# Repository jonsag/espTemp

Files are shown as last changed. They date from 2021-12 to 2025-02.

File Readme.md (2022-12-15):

# espTemp

An ESP-01 module with a DHT22 temperature sensor  
KiCad/espTemp/espTemp.png
Modified from [https://randomnerdtutorials.com/esp8266-dht11dht22-temperature-and-humidity-web-server-with-arduino-ide/](https://randomnerdtutorials.com/esp8266-dht11dht22-temperature-and-humidity-web-server-with-arduino-ide/)

## Hardware

Build according to schematics in KiCAD.  

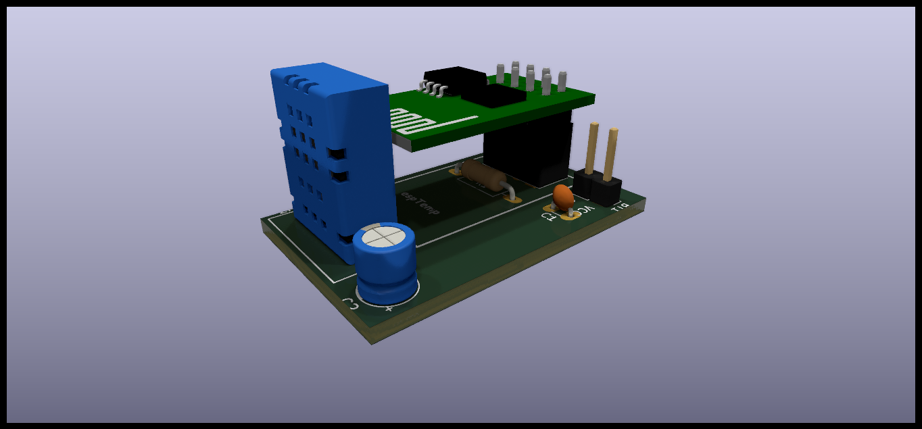
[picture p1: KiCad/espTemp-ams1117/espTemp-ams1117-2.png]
with AMS1117 3dView

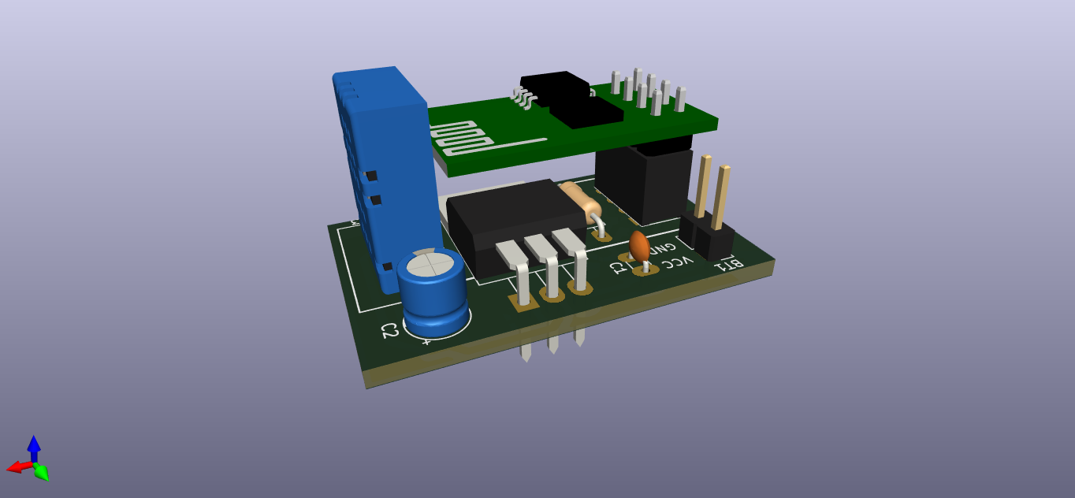
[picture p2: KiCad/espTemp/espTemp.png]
with LM78xx 3dView

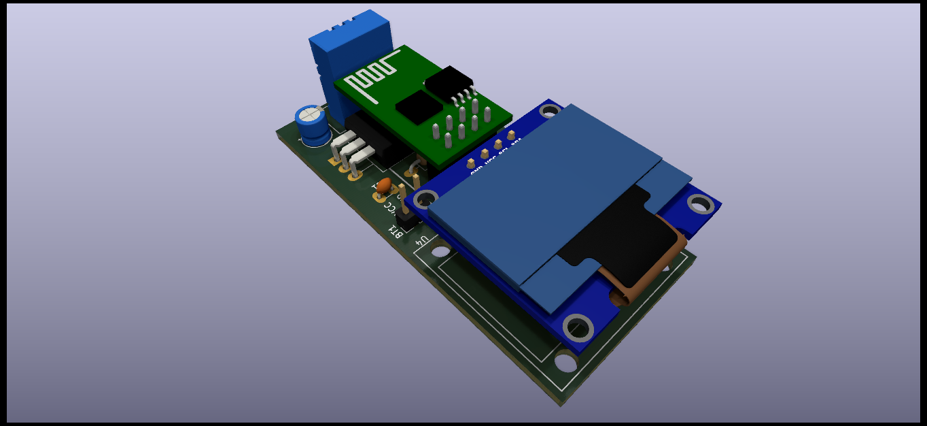
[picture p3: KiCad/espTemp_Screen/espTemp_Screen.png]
with screen 3dView


## Software

Copy file wifiConfig.h.template in espTemp-PIO/src to wifiConfig.h.  
>$ cp espTemp-PIO/src/wifiConfig.h.template espTemp-PIO/src/wifiConfig.h

Edit the new file, entering your SSID and password.  
Compile and upload.  

Connect via serial (while module is still in  programmer) to find out IP and port.  

## Pins on the ESP-01

Pin         Input       Output  
5   GPIO0   pulled up   OK          connected to FLASH button, boot fails if pulled LOW  
2   GPIO1   TX pin      OK          HIGH at boot, debug output at boot, boot fails if pulled LOW  
3   GPIO2   pulled up   OK          HIGH at boot, connected to on-board LED, boot fails if pulled LOW  
7   GPIO3   OK          RX pin      HIGH at boot

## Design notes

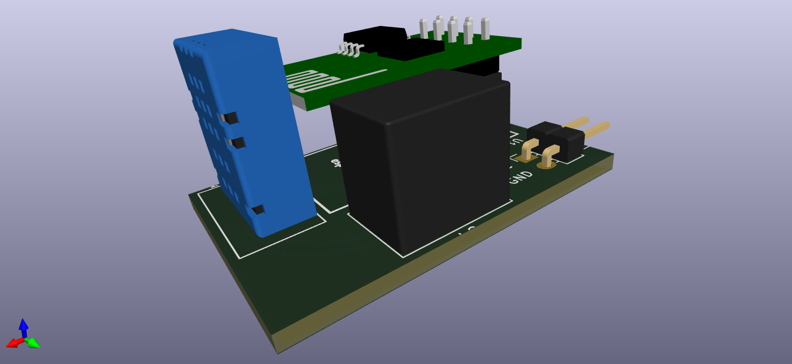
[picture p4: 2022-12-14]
KiCad/espTemp_R-78xx/espTemp_R-78xx.png

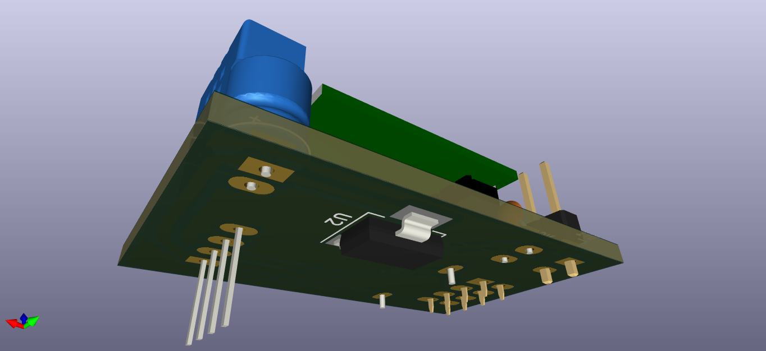
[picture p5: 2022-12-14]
KiCad/espTemp-ams1117/espTemp-ams1117.png

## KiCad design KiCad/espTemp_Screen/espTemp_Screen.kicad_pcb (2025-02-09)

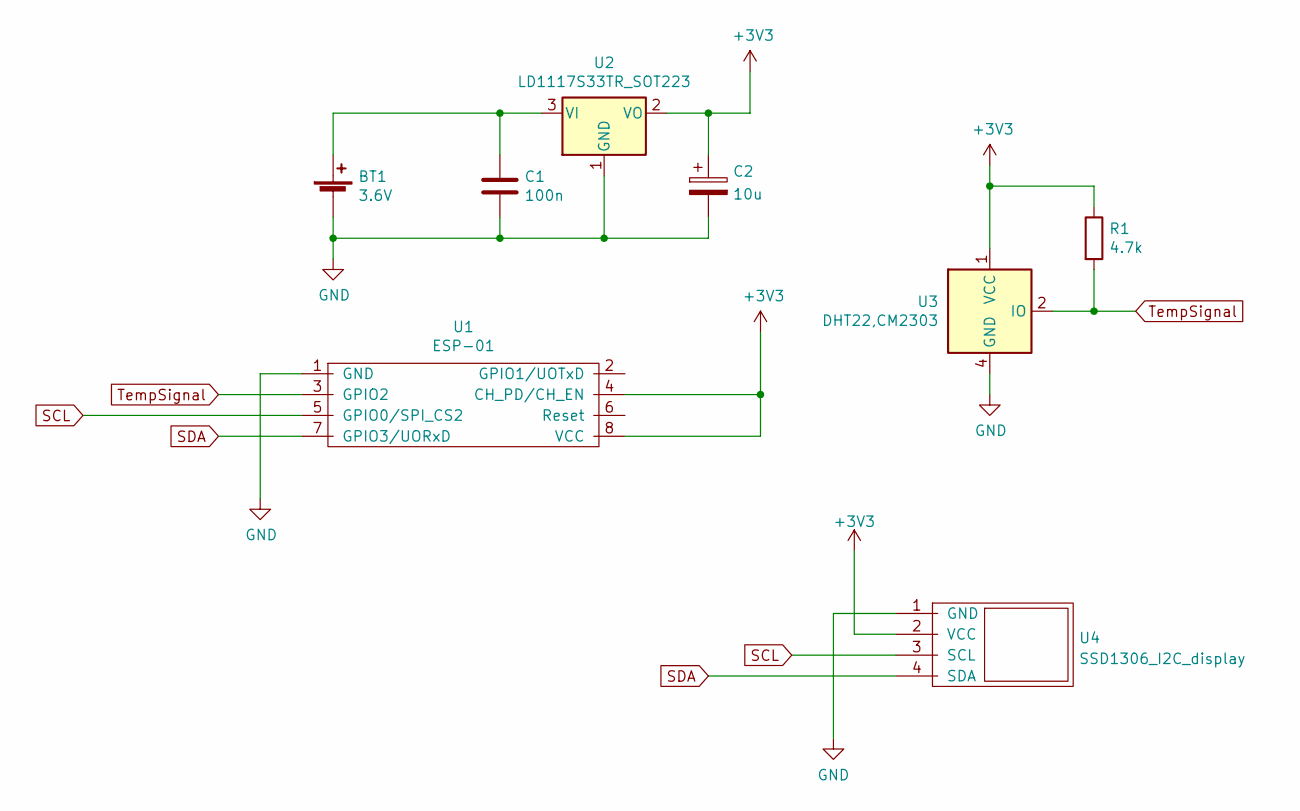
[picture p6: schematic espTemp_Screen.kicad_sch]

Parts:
BT1: 3.6V; 2-pin_power_input_header_larger_pads
C1: 100n; C_Disc_D3.0mm_W1.6mm_P2.50mm_larg
C2: 10u; CP_Radial_D5.0mm_P2.50mm_larger_pads
R1: 4.7k; R_Axial_DIN0207_L6.3mm_D2.5mm_P10.16mm_Horizontal_larger_pa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
U1: ESP-01; ESP-01_w_pin_socket_large
U2: LD1117S33TR_SOT223; TO-220-3_Horizontal_TabDown_large
U3: DHT22,CM2303; DHT22,RHT03,CM2303_100mil_large
U4: SSD1306_I2C_display; SSD1306_I2C_0.96_OLED_display_large

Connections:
+3V3: C2.1, R1.1, U1.4 (CH_PD/CH_EN), U1.8 (VCC), U2.2 (VO), U3.1 (VCC), U4.2 (VCC)
GND: BT1.2 (-), C1.2, C2.2, U1.1 (GND), U2.1 (GND), U3.4 (GND), U4.1 (GND)
unnamed: BT1.1 (+), C1.1, U2.3 (VI)
SCL: U1.5 (GPIO0/SPI_CS2), U4.3 (SCL)
SDA: U1.7 (GPIO3/UORxD), U4.4 (SDA)
TempSignal: R1.2, U1.3 (GPIO2), U3.2 (IO)

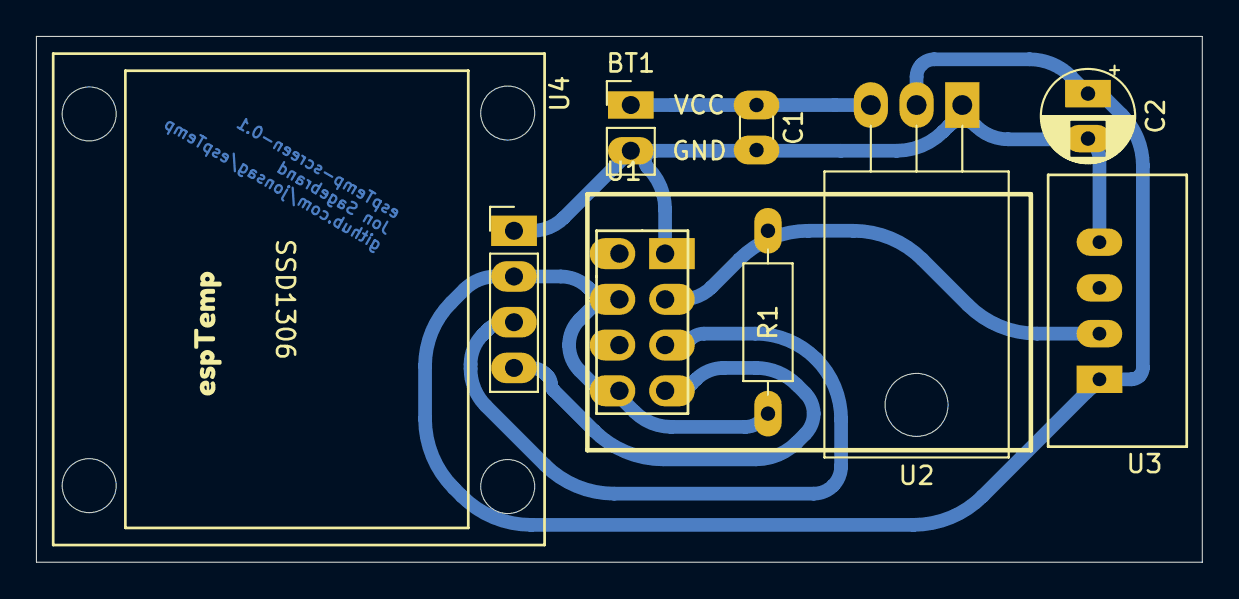
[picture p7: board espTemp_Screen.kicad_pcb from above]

Board: 2 copper layers, 64.8 x 29.2 mm, 9 parts (0 on the bottom side), 6 nets.

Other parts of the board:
kibuzzard-62077BA3: G***; kibuzzard-62077BA3

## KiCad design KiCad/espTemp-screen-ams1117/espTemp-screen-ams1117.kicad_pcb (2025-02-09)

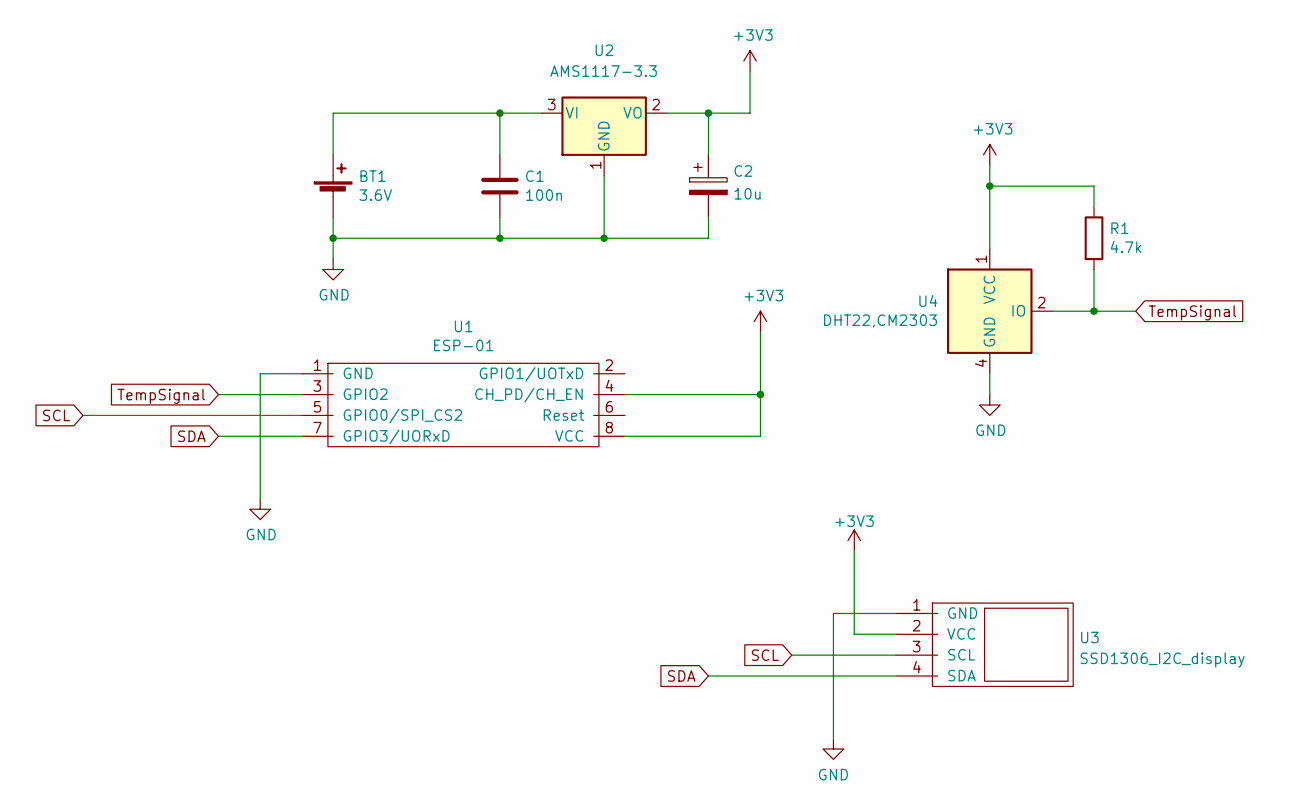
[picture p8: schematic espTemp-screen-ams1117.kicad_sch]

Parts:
BT1: 3.6V; 2-pin_power_input_header_larger_pads
C1: 100n; C_Disc_D3.0mm_W1.6mm_P2.50mm_larg
C2: 10u; CP_Radial_D5.0mm_P2.50mm_larger_pads
R1: 4.7k; R_Axial_DIN0207_L6.3mm_D2.5mm_P10.16mm_Horizontal_larger_pa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
U1: ESP-01; ESP-01_w_pin_socket_large
U2: AMS1117-3.3; SOT-223-3_TabPin2
U3: SSD1306_I2C_display; SSD1306_I2C_0.96_OLED_display_large
U4: DHT22,CM2303; DHT22,RHT03,CM2303_100mil_large

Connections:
+3V3: C2.1, R1.1, U1.4 (CH_PD/CH_EN), U1.8 (VCC), U2.2 (VO), U3.2 (VCC), U4.1 (VCC)
GND: BT1.2 (-), C1.2, C2.2, U1.1 (GND), U2.1 (GND), U3.1 (GND), U4.4 (GND)
unnamed: BT1.1 (+), C1.1, U2.3 (VI)
SCL: U1.5 (GPIO0/SPI_CS2), U3.3 (SCL)
SDA: U1.7 (GPIO3/UORxD), U3.4 (SDA)
TempSignal: R1.2, U1.3 (GPIO2), U4.2 (IO)

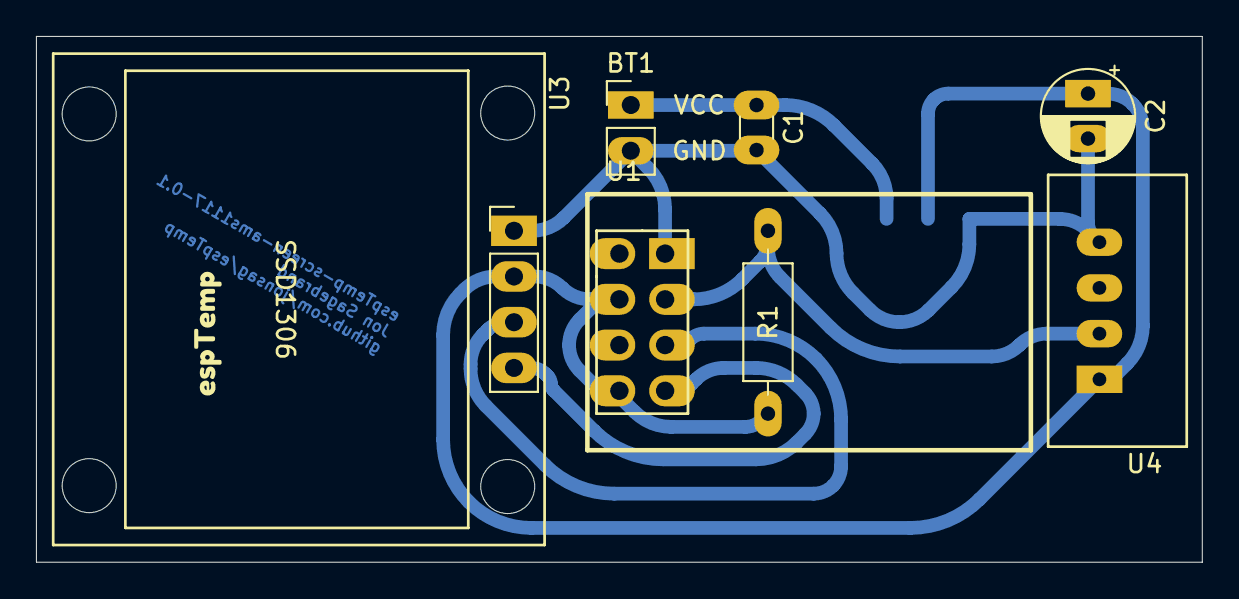
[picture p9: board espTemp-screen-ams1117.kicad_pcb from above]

Board: 2 copper layers, 64.8 x 29.2 mm, 9 parts (1 on the bottom side), 6 nets.

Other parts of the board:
kibuzzard-62077BA3: G***; kibuzzard-62077BA3

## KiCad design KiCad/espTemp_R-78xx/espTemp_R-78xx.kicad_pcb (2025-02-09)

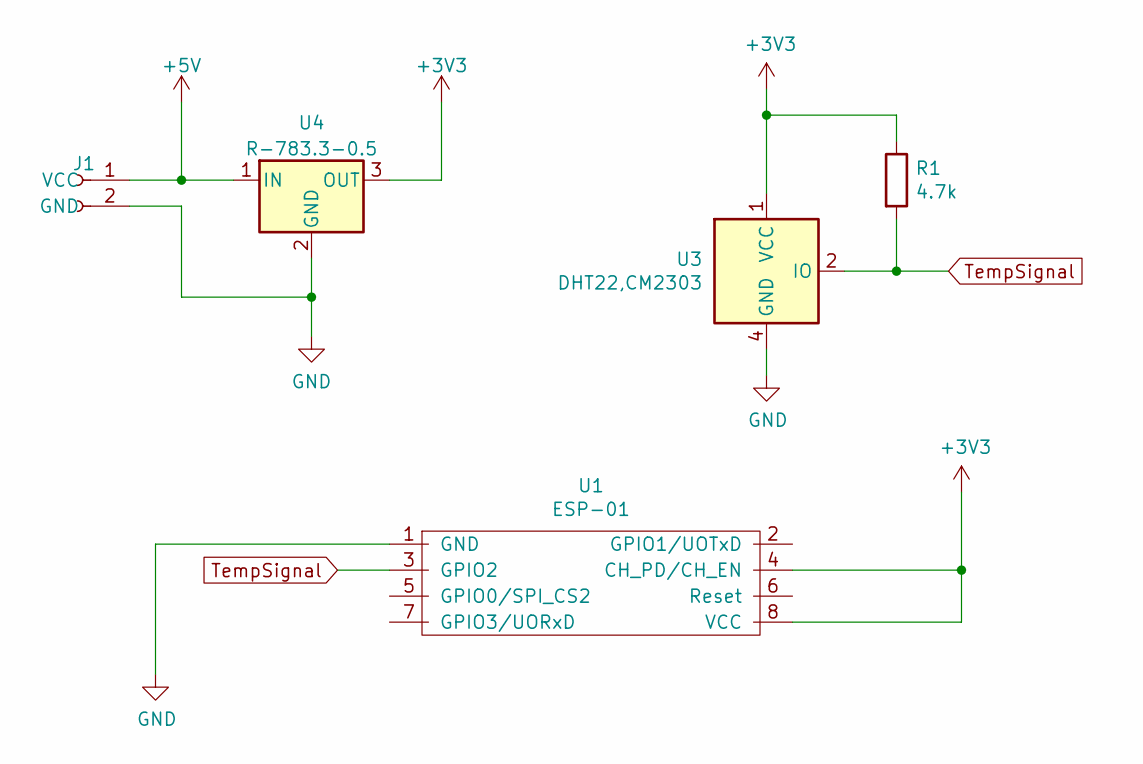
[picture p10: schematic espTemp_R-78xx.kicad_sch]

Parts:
J1: 2-pin_power_input_header; 2-pin Power Input Header angled large
R1: 4.7k; R_Axial_DIN0207_L6.3mm_D2.5mm_P10.16mm_Horizontal_larger_pa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
U1: ESP-01; ESP-01_w_pin_socket_large
U3: DHT22,CM2303; DHT22,RHT03,CM2303_100mil_large
U4: R-783.3-0.5; Converter_DCDC_RECOM_R-78E-0.5_THT

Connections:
+3V3: R1.1, U1.4 (CH_PD/CH_EN), U1.8 (VCC), U3.1 (VCC), U4.3 (OUT)
+5V: J1.1 (VCC), U4.1 (IN)
GND: J1.2 (GND), U1.1 (GND), U3.4 (GND), U4.2 (GND)
TempSignal: R1.2, U1.3 (GPIO2), U3.2 (IO)

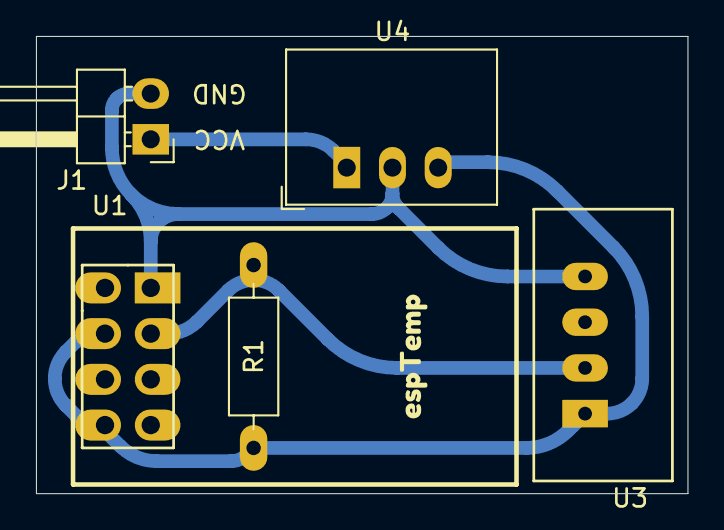
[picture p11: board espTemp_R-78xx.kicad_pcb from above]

Board: 2 copper layers, 36.2 x 25.4 mm, 6 parts (0 on the bottom side), 4 nets.

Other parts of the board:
kibuzzard-62077BA3: G***; kibuzzard-62077BA3

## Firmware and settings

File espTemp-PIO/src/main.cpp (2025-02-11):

/*********
 * Jon Sagebrand
 * Credits to Rui Santos
 * Read his tutorials at
 * https://randomnerdtutorials.com/esp8266-dht11dht22-temperature-and-humidity-web-server-with-arduino-ide/ and
 * https://RandomNerdTutorials.com/esp8266-nodemcu-mqtt-publish-bme680-arduino/
 * https://randomnerdtutorials.com/esp8266-web-server-with-arduino-ide/
 *********/
#include <Arduino.h>

#include "config.h"

/***********
 * Add a file in this directory, called 'secrets.h'
 * You can copy the 'secrets.h.template'
 * This file should include the following lines:
 *
 * #define WIFI_SSID "<your SSID>"
 * #define WIFI_PASSWORD "<your wifi password>"
 *
 * #define MQTT_USER "<username for the mqtt broker>"
 * #define MQTT_PASSWORD "<password for the mqtt broker>"
 *
 * Update these with values suitable for your network.
 ***********/

#include "secrets.h"

#include "wifi.h"

#if MQTT
#include "mqtt.h"
#endif

#include "webServer.h"
#include "dht.h"

#if SCREEN
#include "screen.h"
#endif

void setup()
{
  Serial.begin(serial_speed); // serial port for debugging purposes
  Serial.println("Serial started.");

  /***********
   * Screen
   ***********/
#if SCREEN
  Serial.println("Setting up screen ...");
  Wire.begin(SDA, SCL);

  display.begin(SSD1306_SWITCHCAPVCC, 0x3D);

  // Wire.setClock(400000L);   // uncomment this to set I2C clock to 400kHz

  display.display(); // display the splashscreen
  delay(500);

  display.clearDisplay();

  drawText(1, 10, 10, "Hello World!");
  delay(500);

  display.clearDisplay();
#endif

  /***********
   * DHT config
   ***********/
  Serial.println("Setting up DHT sensor ...");
  dht.setup(dhtPin, DHTesp::dhtType);

  /***********
   * Wifi
   ***********/
#if MQTT
  Serial.println("Setting up wifi ...");
  wifiConnectHandler = WiFi.onStationModeGotIP(onWifiConnect);
  wifiDisconnectHandler = WiFi.onStationModeDisconnected(onWifiDisconnect);
#endif

  /***********
   * MQTT
   ***********/
#if MQTT
  Serial.println("Setting up mqtt ...");
  mqttClient.onConnect(onMqttConnect);
  mqttClient.onDisconnect(onMqttDisconnect);
  // mqttClient.onSubscribe(onMqttSubscribe);
  // mqttClient.onUnsubscribe(onMqttUnsubscribe);
  // mqttClient.onMessage(onMqttMessage);
  mqttClient.onPublish(onMqttPublish);
  mqttClient.setServer(MQTT_HOST, MQTT_PORT);
  // mqttClient.setCredentials(MQTT_USER, MQTT_PASSWORD);
  mqttClient.setCredentials(MQTT_USER, MQTT_PASSWORD).setClientId(device_name);
#endif

  Serial.println("Connecting to wifi ...");
  connectToWifi();

  /***********
   * Chip ID & topics
   ***********/
  get_chip_ID();

  /***********
   * Web server
   ***********/
  Serial.println("Setting up web server ...");
  // Route for root / web page
  server.on("/", HTTP_GET, [](AsyncWebServerRequest *request)
            { request->send_P(200, "text/html", index_html, processor); });

  server.on("/temperature", HTTP_GET, [](AsyncWebServerRequest *request)
            { request->send_P(200, "text/plain", String(t).c_str()); });
  server.on("/humidity", HTTP_GET, [](AsyncWebServerRequest *request)
            { request->send_P(200, "text/plain", String(h).c_str()); });

  server.on("/count.php", HTTP_GET, [](AsyncWebServerRequest *request)
            { request->send_P(200, "text/plain", String(numberOfSensors).c_str()); });

  server.on("/chipID", HTTP_GET, [](AsyncWebServerRequest *request)
            { request->send_P(200, "text/plain", String(chip_id_HEX).c_str()); });

  // Send a GET request to <IP>/get?message=<message>
  server.on("/name.php", HTTP_GET, [](AsyncWebServerRequest *request)
            {
              String message;
              if (request->hasParam(PARAM_MESSAGE))
              {
                message = request->getParam(PARAM_MESSAGE)->value();
              }
              else
              {
                message = "No message sent";
              }
              //request->send(200, "text/plain", "Hello, GET: " + message);
              request->send(200, "text/plain", String(device_name).c_str()); });

  server.on("/value.php", HTTP_GET, [](AsyncWebServerRequest *request)
            {
              String message;
              if (request->hasParam(PARAM_MESSAGE))
              {
                message = request->getParam(PARAM_MESSAGE)->value();
              }
              else
              {
                message = "No message sent";
              }
              request->send(200, "text/plain", String(t).c_str()); });

  server.onNotFound(notFound);

  Serial.println("Starting web server ...");
  server.begin(); // start server

  Serial.println("Setup finished.");
  Serial.println("Entering main loop ...");
  Serial.println();
}

void loop()
{
  unsigned long currentMillis = millis();

  if (currentMillis - previousMillis >= interval)
  {
    previousMillis = currentMillis; // save the last time you updated the DHT values

    Serial.println("Reading temperature and humidity ...");

    float newT = dht.getTemperature(); // read temperature as Celsius (the default)

    if (isnan(newT))
    { // if temperature read failed, don't change t value
      Serial.println("Failed to read temperature from DHT sensor!");
    }
    else
    {
      t = newT;

      uint16_t packetIdPub1 = mqttClient.publish(MQTT_PUB_TEMP, 1, true, String(t).c_str());
      Serial.printf("Publishing on topic %s at QoS 1, packetId: %i ", MQTT_PUB_TEMP, packetIdPub1);
      Serial.printf("Message: %.2f \n", t);

      Serial.print("Temperature: ");
      Serial.println(t);
    }

    float newH = dht.getHumidity(); // read Humidity

    if (isnan(newH))
    { // if humidity read failed, don't change h value
      Serial.println("Failed to read humidity from DHT sensor!");
    }
    else
    {
      h = newH;

      uint16_t packetIdPub2 = mqttClient.publish(MQTT_PUB_HUM, 1, true, String(h).c_str());
      Serial.printf("Publishing on topic %s at QoS 1, packetId: %i ", MQTT_PUB_HUM, packetIdPub2);
      Serial.printf("Message: %.2f \n", h);

      Serial.print("Humidity: ");
      Serial.println(h);
    }
  }
}

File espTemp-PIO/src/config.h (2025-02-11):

// Import required libraries
#include <Arduino.h>

#include <Hash.h>
#include <Adafruit_Sensor.h>

#define SCREEN 0 // 1 if screen is present
#define MQTT 1   // 1 to send values to an mqtt broker

/***********
 * Sensors
 ***********/
#define numberOfSensors 1
#define device_name "ESP-2388C5" // ESP-01
//#define device_name "ESP-35E561" // ESP-01
//#define device_name "ESP-E0569F" // nodeMCU v2

/***********
 * DHT config
 ***********/
/* DHT type, valid types are:
AUTO_DETECT Try to detect which sensor is connected (default if 2nd parameter is not used)
DHT11
DHT22
AM2302 (Packaged DHT22)
RHT03 (Equivalent to DHT22)
*/
#define dhtType DHT22

// Connect DHT sensor to GPIO2
const int dhtPin = 2;

/***********
 * Web server
 ***********/
#define serverPort 8081

/***********
 * Screen
 ***********/
#if SCREEN
#include <Wire.h>
#include <Adafruit_GFX.h>
#include <Adafruit_SSD1306.h>

// set I2C pins (SDA = GPIO3, SCL = GPIO0), default clock is 100kHz
#define SDA 3
#define SCL 0

#define OLED_RESET 1 // define SSD1306 OLED reset (TX pin)

Adafruit_SSD1306 display(OLED_RESET);

#if (SSD1306_LCDHEIGHT != 64)
#error("Height incorrect, please fix Adafruit_SSD1306.h!");
#endif
#endif

/***********
 * MQTT
 ***********/
#if MQTT
#define MQTT_HOST IPAddress(192, 168, 68, 173) // IP of the mqtt broker
#define MQTT_PORT 1883                         // port the broker is listening to

String config_payload;

// MQTT Topics
#define MQTT_TOP_TOPIC "environment"

#define MQTT_PUB_TEMP "ESP-2388C5/temperature"
#define MQTT_PUB_HUM "ESP-2388C5/humidity"

//#define MQTT_PUB_TEMP "ESP-35E561/temperature"
//#define MQTT_PUB_HUM "ESP-35E561/humidity"

//#define MQTT_PUB_TEMP "ESP-E0569F/temperature"
//#define MQTT_PUB_HUM "ESP-E0569F/humidity"

#endif

/***********
 * Misc
 ***********/
// current temperature & humidity, updated in loop()
float t = 0.0;
float h = 0.0;

unsigned long previousMillis = 0; // will store last time DHT was updated

// Updates DHT readings every 10 seconds
#define interval 10000

// Serial speed
#define serial_speed 115200

uint32_t chip_id;
String chip_id_HEX;

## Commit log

2021-12-01 change pin and sensor type
2021-12-14 larger vias
    [espTemp.kicad_pcb]
2021-12-14 now dht22
    [espTemp.kicad_pcb, espTemp.sch]
2021-12-14 DHT22, DHT type
    [espTemp.kicad_pcb, espTemp.sch]
2021-12-15 100mil DHT on PCB
    [espTemp.kicad_pcb, espTemp.sch]
2021-12-26 KiCAD 6.0
2021-12-27 KiCAD 6.x
    [espTemp.kicad_pcb, espTemp.kicad_sch]
2021-12-27 fixed kicad
    [espTemp.kicad_pcb, espTemp.kicad_sch]
2021-12-27 3d view
    [espTemp.kicad_pcb, espTemp.kicad_sch]
2022-04-23 readme and pcb
    [espTemp.kicad_pcb]
2022-04-24 other regulator solutions
    [espTemp-ams1117.kicad_pcb, espTemp-ams1117.kicad_sch, espTemp_R-78xx.kicad_pcb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]
2022-04-24 pcb with screen
    [espTemp_Screen.kicad_pcb, espTemp_Screen.kicad_sch]
2022-12-15 new pcb, readme
    [espTemp-ams1117.kicad_pcb, espTemp-screen-ams1117.kicad_pcb, espTemp-screen-ams1117.kicad_sch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]
2025-02-09 kicad v8
    [espTemp-ams1117.kicad_pcb, espTemp-ams1117.kicad_sch, espTemp-screen-ams1117.kicad_pcb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]
2025-02-09 major rework, implementing mqtt
    [config.h, main.cpp]
